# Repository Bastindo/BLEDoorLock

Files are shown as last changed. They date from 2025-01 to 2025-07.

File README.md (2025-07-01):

# BLE Door Lock

## What is this?

This is a Arduino Nano ESP32 based door lock, which controls a MG90S servo motor over Bluetooth Low Energy (BLE), built as part of the 2024 Project Week Hackathon of the FSR Elektrotechnik of the University of Rostock. This project includes user authentication and secure Bluetooth communication using the NimBLE stack.

## Building

This project uses PlatformIO.

You can just use the VSCode extension, but the project can also be built with the PlatformIO CLI tool.

To install it, use pip:
`pip install -U platformio`

Then follow these instructions:

1. Clone the repository and cd into it:

```
git clone https://github.com/Bastindo/HackathonBLE
cd HackathonBLE
```

2. Build a firmware image with this command:

```
pio run
```

## Installing

If you never installed this project on your device, you need to prepare the board for filesystem creation. You only need to do this once.

To do so, follow this tutorial: https://docs.arduino.cc/tutorials/nano-esp32/spiff/

Or

```
pio run --target buildfs
pio run --target uploadfs
```

After that (or if you've done the filesystem part already) run `pio run -t upload` to flash the firmware image to your device.

## Usage

### Hardware setup servo

Connect your servo PWM pin (yellow/orange wire) to the D2 pin on the Arduino. This pin can be configured in `src/config.h`. The servo also needs connections to 5V VCC and GND. You can use the VBUS and GND pins on the Arduino for this.

### Hardware setup relay

Connect your relay s pin to the D2 pin on the Arduino. This pin can be configured in `src/config.h`. The relay also needs connections to 3.3V or 5V VCC (see your relay specification) and GND. You can use the 3.3V or VBUS and GND pins on the Arduino for this.

### BLE

You can use the "nRF Connect" app on your phone to talk to the door lock. To pair the device, you will need a PIN. The default PIN is 123456, but it can be changed in `src/config.h`.

The firmware provides two BLE services, one for opening/closing the lock and one for adding new users.

The first service has three characteristics: Username, Password and Lockstate.
Just send your username and password to the first two characteristics and your lockstate to the third one to interact with the door lock as a user.

The lockstate can be:

- 0 for closing the door
- 1 for opening the door
- 2 for opening the door for a short period of time (default: 10 seconds)

The second service can be used to add or remove user accounts and provides five characteristics: Admin Username, Admin Password, Username, Password and Admin Action.

The admin action can be:

- 0 for removing a user
- 1 for adding a new user (make sure to set a password)

### BLE Examples

To get the actual UUIDs of the characteristics shown in these examples see `src/config.h`.

To authorize and open the door for 10 seconds send the following values to the following characteristics (in order):

```
Username -> "your_username"
Password -> "your_password1234"
Lockstate -> "2"
```

To authorize as an admin and add a new user:

```
AdminUsername -> "your_admin_name"
AdminPassword -> "your_admin_pw1234"
Username -> "user_to_be_created9876"
Password -> "new_user_pw9876"
AdminAction -> "1"
```

To authorize as an admin and remove a user (note that you don't need to specify a password):

```
AdminUsername -> "your_admin_name"
AdminPassword -> "your_admin_pw1234"
Username -> "user_to_be_removed9876"
AdminAction -> "0"
```

Admin accounts can be added via serial. See below for an example.

### Serial

The firmware provides a command shell and a log on the USB serial interface.
This can be used to add or remove admin or user accounts and debug various stuff.
Type `help` in the serial console to see a list of commands.

### [Serialscripts](serialscripts/README.md)

Scripts to manage users, and generate QR-Codes for the [APP](https://github.com/UwUTastisch/BLEDoorLock-App).

### Serial examples

Add a new admin account:

```
addadmin new_admin_name123 password1234
```

Add a new user:

```
adduser new_user123 password1234
```

Remove an admin account:

```
removeadmin admin_name123
```

List all users:

```
cat users.csv
```

List all admins:

```
cat admins.csv
```

### Configuration

Configuration can be done by editing `src/config.h`.

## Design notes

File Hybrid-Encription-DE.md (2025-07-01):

# ESP-Doorlock

Hier ist der Sachverhalt aus dem handschriftlichen Diagramm digital und strukturiert dargestellt:

---

### 🔐 **Hybrid-Verschlüsselung mit RSA und AES**

#### **Ablaufdiagramm**

```mermaid
sequenceDiagram
    participant C as Client
    participant S as Server

    Note over C,S: Hybridverschlüsselung (RSA + AES)

    Note over C:  RSA-Key aufgefüllt mit 0 als String

    C->>S: Activate UUID_KEY_CHARACTERISTIC "df5ba2aa-c90c-4c90-8c5f-059f62ff51a1" notify

    C->>+S: RSA-pub Schlüssel senden

    Note over S: AES Session-Key generieren<br/>AES-GCM Modus mit SHA-256<br/>mit preshared IV (Initialisierungsvektor)
    Note over S: AES-Key mit public key nach (RSA PKCS1 v2.1 OAEP) verschlüssen

    S->>-C: Notify change Encrypted-AES-Key

    Note over C: Nachricht mit AES-GCM<br/>verschlüsseln (16 Bytes Daten +<br/>16 Bytes Authentifizierungstag)

    C->>+S: Verschlüsselte Nachricht senden +  Authentifizierungstag
```

---

### ✳️ Details zur Implementierung

#### **RSA**

- **Modus**: `RSA PKCS#1 v2.1 (OAEP)`
- **Hash-Funktion**: `SHA-256`
- **Hinweis**: **NICHT** `v1.5` verwenden → **Bleichenbacher-Angriff** möglich

#### **AES**

- **Modus**: `AES-GCM`
- **IV (Initialisierungsvektor)**:

  - Wird **einmalig zufällig** generiert und dokumentiert

- **Tag (Authentifizierungs-Tag)**:

  - Wird **mit dem verschlüsselten Text** übergeben
  - Format: `16 Byte verschlüsselte Daten + 16 Byte Tag`

```c++
uint8_t m_aes_iv[12] = {0x46, 0x61, 0x63, 0x68, 0x73, 0x63,
                        0x68, 0x61, 0x66, 0x74, 0x45, 0x54};
```

---

Möchtest du daraus auch eine Grafik im Stil eines Blockdiagramms, z. B. als SVG oder PNG?

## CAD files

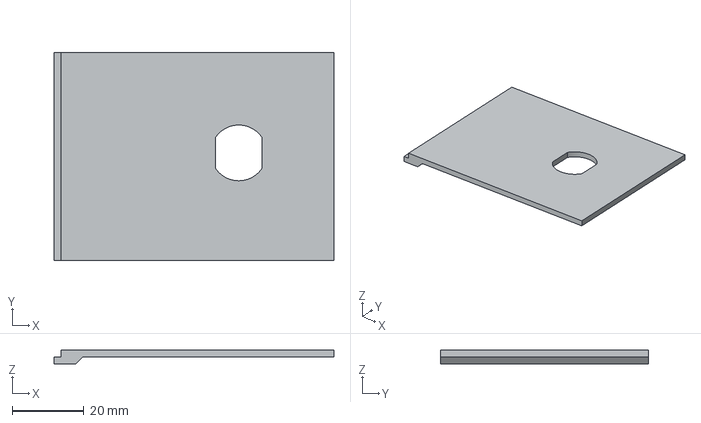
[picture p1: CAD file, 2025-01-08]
3D Files/top.3mf
77.9 x 57.9 x 4.00 mm

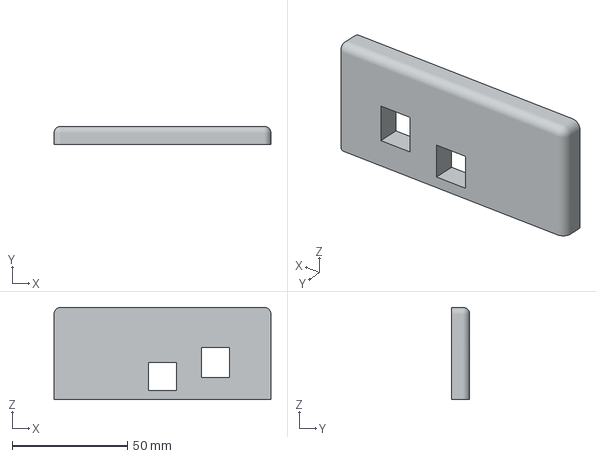
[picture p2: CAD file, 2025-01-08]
3D Files/front.3mf
94.0 x 8.00 x 40.0 mm

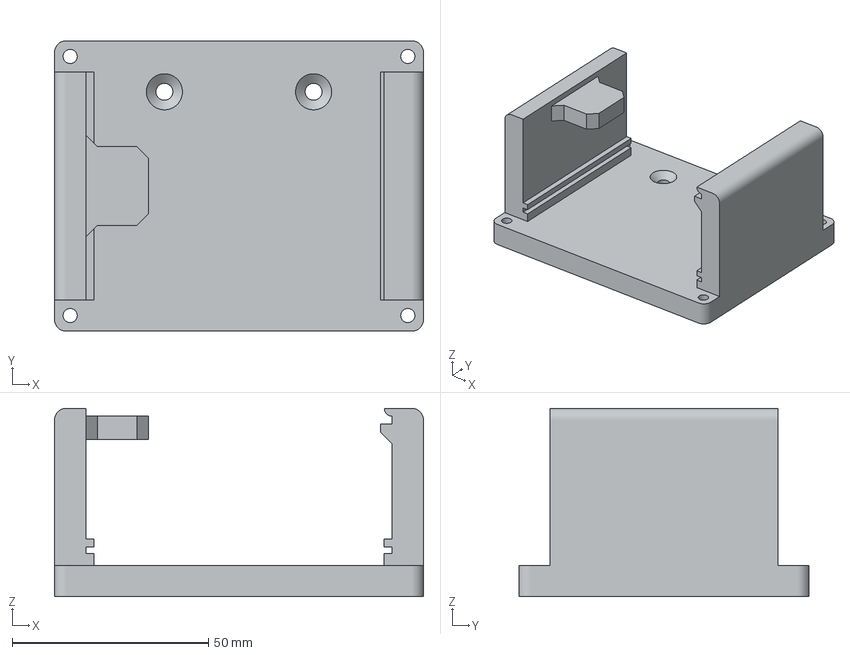
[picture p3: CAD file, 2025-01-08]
3D Files/base.3mf
94.0 x 74.0 x 48.0 mm

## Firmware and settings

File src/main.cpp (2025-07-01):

#include <Arduino.h>

#include "ble_server2.h"
#include "cmd.h"
#include "config.h"
#include "log.h"
#include "opendoor.h"
#include "user_auth.h"
#include "wifi_client.h"

void setup() {
  Serial.begin(115200);
#if DEBUG_MODE == 1
  while (!Serial && !Serial.available()) {
  }
#endif

  setupLog();

  logInfoln("Starting up...");
  uint32_t freq = getCpuFrequencyMhz();
  String freqString = "CPU Frequency: " + String(freq) + "MHz\n";
  logInfo(freqString.c_str());
  setupBLE();
  setupOpener();
#if (WIFI == 1)
  setupWiFi();
#endif
  setupUserAuth();
  setupFileLog();
  setupCmd();
}

void loop() {
  cmdLoop(DEBUG_MODE);
  BLE.poll();
}

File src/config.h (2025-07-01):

#ifndef CONFIG_H
#define CONFIG_H

/* ######## Debug Mode ######## */
//
// Debug mode waits for serial connection on boot and provides additional serial
// commands (open, close, shortopen)
#define DEBUG_MODE 1
//

/* ######## Logging ######## */
//
// Log level (possible options: LOG_LEVEL_{SILENT, FATAL, ERROR, WARNING, INFO,
// TRACE, VERBOSE}, use ERROR if you only want to log user authentications)
#define LOG_LEVEL LOG_LEVEL_VERBOSE
//

/* ######## Door Opener ######## */
//
// Connect servo PWM line to the GPIO pin configured here (2 usually corresponds
// to D2) new pin is D13
#define SERVO_PIN 2
#define SERVO_OPEN_ANGLE 80   // angle to open the door
#define SERVO_CLOSE_ANGLE 90  // angle to close the door (Default state)
//
// Connect relay control line to the GPIO pin configured here (13 usually
// corresponds to D13)
#define RELAY_PIN 13
//

/* ######## Wifi ######## */
// set to 1 to activate WiFi
#define WIFI 0

/* ######## WiFi Client ######## */
// network credentials
#define WIFI_SSID ""
#define WIFI_PASSWORD ""

/* ######## HTTP logging ######## */
#define HTTP_TARGET1 192  // IP of the target for logging
#define HTTP_TARGET2 168
#define HTTP_TARGET3 178
#define HTTP_TARGET4 236

#define HTTP_PORT 64000  // Port of the target for logging

/* ######## BLE server ######## */
// BLE name
#define BLE_NAME "NimBLE Servo Lock 4"
//
// time interval for the Short Unlock function
#define SHORT_UNLOCK_TIME 3000  // ms
//
// Logout time in ms
#define LOGOUT_TIME 12000
//
// UUIDs (usually shouldn't be changed)
#define UUID_USER_SERVICE "2ff7c135-5010-497b-a054-cea3984c7cc9"
#define UUID_ADMIN_SERVICE "be527357-c722-4367-aac3-bddef6a6f6e2"
#define UUID_CRYPTO_SERVICE "1c970e06-8094-4b83-a54b-a465396ebaa8"
//
#define UUID_USER_CHARACTERISTIC "5d3932fa-2901-4b6b-9f41-7720976a85d4"
#define UUID_PASS_CHARACTERISTIC "dd16cad0-a66a-402f-9183-201c20753647"
#define UUID_LOCKSTATE_CHARACTERISTIC "05c5653a-7279-406c-9f9e-df72aa99ca2d"
//
#define UUID_ADMIN_CHARACTERISTIC "68f2b041-dc1e-42af-af96-773a2386b08b"
#define UUID_ADMINPASS_CHARACTERISTIC "394e8790-109b-47c0-aa67-1aa61c02188b"
#define UUID_ADDUSER_CHARACTERISTIC "92acb83b-ff02-43ec-9adb-16755eb8ce9b"
#define UUID_ADDPASS_CHARACTERISTIC "8de8c0c0-0568-40a0-a52b-520a6e772503"
#define UUID_ADMINACTION_CHARACTERISTIC "b1d86fdf-7d5d-49b7-8da7-b02bd53bdb0a"
//
#define UUID_KEY_CHARACTERISTIC "df5ba2aa-c90c-4c90-8c5f-059f62ff51a1"

/* ######## CMD ######## */
//
// usually shouldn't be changed
#define CMD_BUFFER_SIZE 256
//

#define VALID_USERNAME_CHARACTER \
  "abcdefghijklmnopqrstuvwxyzABCDEFGHIJKLMNOPQRSTUVWXYZ0123456789_"

/* ######## LockState ######## */

// Enum for the lock state
// do not change the values of the enum!
enum LockState { LOCKED = 0, UNLOCKED = 1, SHORT_UNLOCK = 2 };

#endif

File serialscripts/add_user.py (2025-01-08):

import os
import sys
import random
import string
import json
import qrcode
import tempfile
from dotenv import load_dotenv
from list_users import list_users
from send_command import send_command
from PIL import Image
import matplotlib.pyplot as plt

# Load environment variables from .env file
load_dotenv()

LOCK_ID = os.getenv('LOCK_ID', 'default_lock_id')  # Replace with your actual lock ID
DEBUG = os.getenv('DEBUG', 'false').lower() == 'true'

def generate_password(length=12):
    characters = string.ascii_letters + string.digits
    password = ''.join(random.choice(characters) for i in range(length))
    return password

def user_exists(username):
    users = list_users()
    return any(user.username == username for user in users)

def add_user(username):
    password = generate_password()
    add_user_cmd = f"adduser {username} {password}"
    
    if user_exists(username):
        print(f"User '{username}' already exists in the database.")
    else:
        send_command(add_user_cmd)
        print(f"User '{username}' added successfully.")
        
        json_data = {
            "lockId": LOCK_ID,
            "password": password,
            "userName": username,
            "lockName": "NimBLE Servo Lock 3",
            "isAdmin": False,
            "color": None
        }
        
        json_string = json.dumps(json_data)
        if DEBUG:
            print(f"JSON Data: {json_string}")
        
        # Create a temporary file for the QR code
        with tempfile.NamedTemporaryFile(delete=False, suffix=".png") as temp_qr_file:
            qr_code = qrcode.make(json_string)
            qr_code.save(temp_qr_file.name)
            qr_code_file = temp_qr_file.name
        
        print("QR Code generated.")
        
        try:
            # Display the QR code image using Pillow and matplotlib
            img = Image.open(qr_code_file)
            plt.imshow(img)
            plt.axis('off')
            plt.show()
            
            # Wait for the user to close the image viewer
            
            #input("Press Enter after scanning the QR code to delete the file...")
        except Exception as e:
            print(f"Error displaying QR code: {e}")
        finally:
            # Delete the QR code file
            os.remove(qr_code_file)
            print("QR Code file deleted.")

def main(username):
    add_user(username)

if __name__ == "__main__":
    if len(sys.argv) != 2:
        print("Usage: python add_user.py <username>")
        sys.exit(1)

    username = sys.argv[1]
    main(username)

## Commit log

2024-05-21 Servo setup
2024-05-22 Switch to NimBLE for bluetooth stack
2024-05-23 Added User Auth
    [partitions.csv]
2024-07-12 refactor: Update code to use "opendoor" module for controlling the door instead of "servo"
2024-07-12 Refactor and Repair timer
2024-08-19 Crashing version of Client kick after delay
    [config.h, opendoor.cpp]
2025-06-06 Add compilment option for esp32dev boards
    [partitions_esp32dev.csv]
2025-06-15 Adding servo back
